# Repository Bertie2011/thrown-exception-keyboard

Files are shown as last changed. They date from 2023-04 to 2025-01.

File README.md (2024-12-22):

# ThrownException Keyboard
This repository documents all the details of my every-day keyboard and keymap.
> I use both Bertie2011 and ThrownException as online nicknames

The list of sections below will start with the keymap and QMK libraries, followed by each of the keyboards I have built (newest first).

**Click on any of the images below for more information!**

## Keymap
Many keymaps make use of holding keys to distinguish from their tap behavior. However, holding keys really sucks! For me it feels like tapping two keys is less effort than holding a key. So the philosophy behind the keymap is to be **strictly tap only**. If you're curious about how that's possible and which tricks were pulled to make it easier to use click the image below.

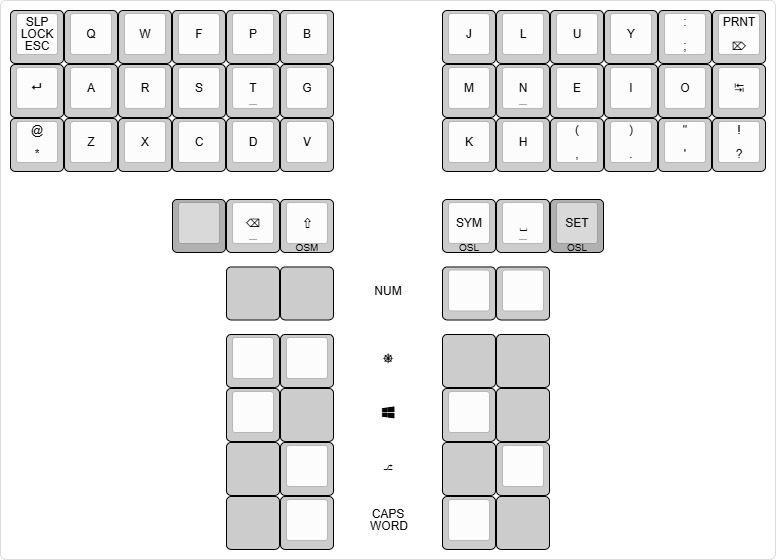
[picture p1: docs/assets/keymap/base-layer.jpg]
Keymap


## QMK Libraries
As a programmer, I love customizing QMK to the point where my keymap.c was feeling a bit too cramped to fit all the custom code. I have isolated my keymap features into seperate source files (aka "mini QMK libraries", aka "bags of tricks") so that others can use them too.

[View QMK Libraries](/qmk-lib/README.md)

## Aurora Corne V1.1 - splitkb.com
With frequent moving of the keyboard between home and work, the rotary encoders were the first to break. I also didn't get much use out of the trackpad, since it requires lifting your hand and at that point you might as well reach for the mouse. A break in the audio jack connections was the final straw. It was time for a new keyboard and I have been wanting a 6th column for a while, so coming from a trusted vendor, the choice for the Aurora Corne was made.

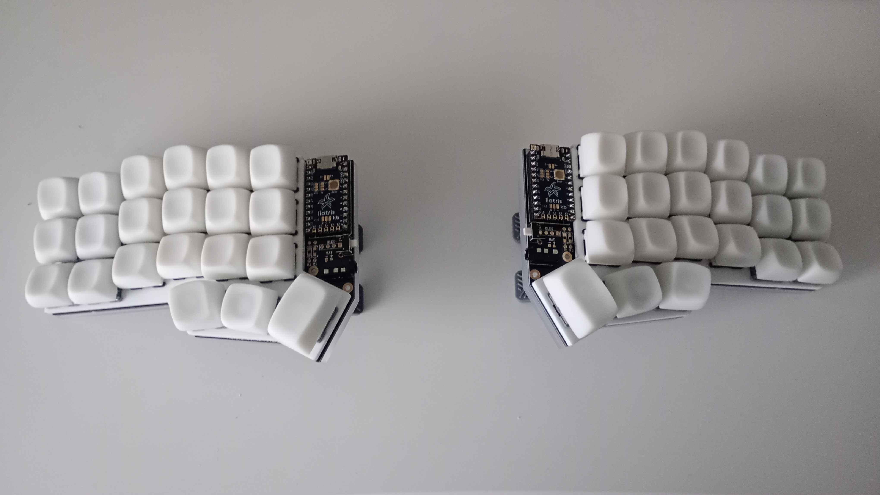
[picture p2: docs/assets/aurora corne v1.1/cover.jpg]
Aurora Corne V1.1


## Dilemma V2 - Bastard Keyboards
Since getting my first split keyboard I never stopped trying to optimize my keymap to the point that the most noticeable discomfort was having to switch over to the mouse every now and then. I tried mouse keys, but could never get used to them so I started looking at the keyboards offered on bastardkb.com. The OLED displays were only used for layer/mod indicators, which I thought would be easier to spot if the keys themselves lit up as indicators with RGB. Throw in rotary encoders which I didn't have before and the decision was made.

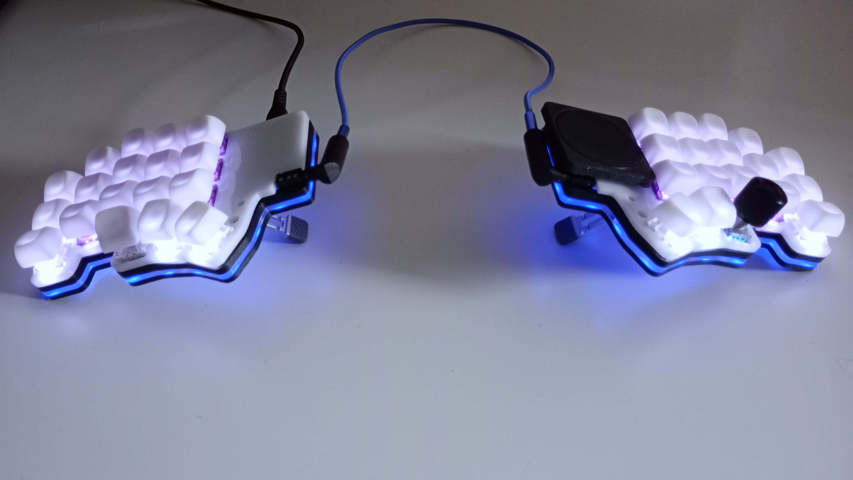
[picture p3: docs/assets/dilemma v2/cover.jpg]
Dilemma V2


## Kyria rev2.0 - splitkb.com
As a programmer I need to be able to type comfortably for many years. To avoid RSI related problems in the future, I wanted to stay ahead and get a more ergonomic keyboard. It was perfect timing, because I was transitioning from a laptop to a gaming PC at the same time, so I needed a new keyboard anyways.

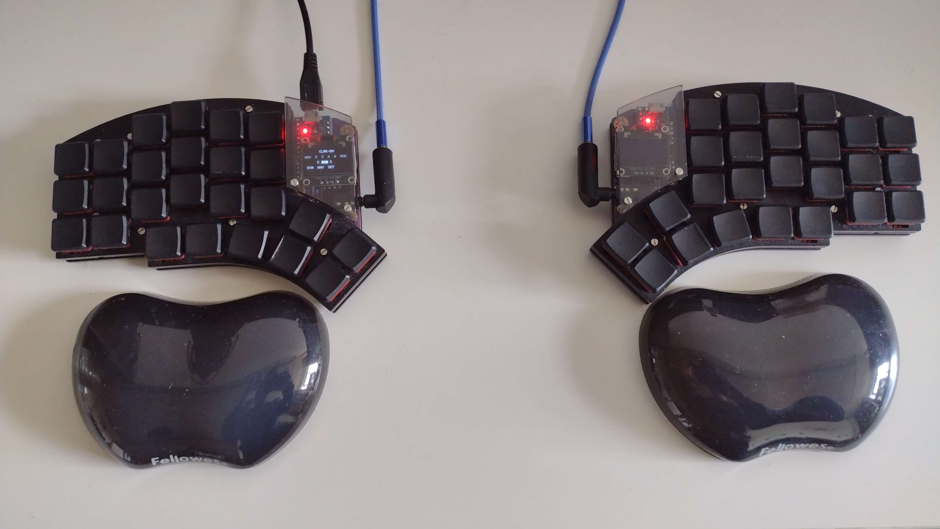
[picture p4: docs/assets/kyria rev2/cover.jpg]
Kyria rev2


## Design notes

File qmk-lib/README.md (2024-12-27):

# QMK Libraries

While working on customizing my keymap I have isolated some parts of code so they could be reused by others. Check out the table below for a list of features you can start using yourself:

Feature|Description
--:|:--
[RGB Layers](/qmk-lib/rgb-layers/)|Allows you to easily define color codes per key per layer, Ergodox EZ configurator style!
[OSM](/qmk-lib/osm/)|My own implementation of one shot modifiers, swapping out the timeout timer with a reset button and using real modifiers that the operating system picks up on as soon as the modifier key is pressed.
[Zones](/qmk-lib/zones/)|Splitting up a layer into multiple others and adding some custom code on top can allow you to repeat keypresses on one layer, while still having access to the base layer when you need it.<br><br>Unfortunately this feature only has docs with code examples and doesn't come with a simplified library that you can download.
[Utility Functions](/qmk-lib/utility-functions/)|A few miscellaneous functions, currently only consisting of improved (base) layer detection functions.

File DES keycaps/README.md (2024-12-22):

The keycaps I'm using have a DES profile. The original design files are hosted at [pseudoku/PseudoMakeMeKeyCapProfiles](https://github.com/pseudoku/PseudoMakeMeKeyCapProfiles), which were then exported as STL, touched up and uploaded at [sporkus/PseudoMakeMeKeyCapProfiles](https://github.com/sporkus/PseudoMakeMeKeyCapProfiles). I made some modifications so that I could order them from a resin printing service online.

Modifications:
- After opening them in the often already installed Microsoft 3D Builder app, I clicked on the popup that appears to "repair" each of the files.
- Added some supports for resin prints.
- Combined models of various files together for the Corne expansion file.

After printing, cleaning up any left-over supports is easiest by taking some scissors and placing each leg on either side of one of the keycap walls underneath the support strands. Then use the scissors as a lever to push the support material off. Optionally sand the bottom of the keycap afterwards.

## File combinations
By printing or ordering certain combinations of files you can get yourself a full keycap set.

* Dilemma or other 5x3+3 keyboards
    * [1x 10 Row 2](./DES_r2_1.00u_x10.stl)
    * [1x 10 Row 3](./DES_r3_1.00u_x10.stl)
    * [1x 10 Row 4](./DES_r4_1.00u_x10.stl)
    * [1x Ergo Fanned Thumb Set](./DES_thumb_ergo_1u_fanned.stl)
*  (Aurora) Corne, 5x3+3 or 6x3+3 versions
    * [1x 10 Row 2](./DES_r2_1.00u_x10.stl)
    * [1x 10 Row 3](./DES_r3_1.00u_x10.stl)
    * [1x 10 Row 4](./DES_r4_1.00u_x10.stl)
    * For 6x3: [1x 6 Column Set](./DES_column_r2r3r4_1.00u_x6.stl)
    * [1x Corne Thumb Set](./DES_thumb_corne_high_pro_x2.stl)

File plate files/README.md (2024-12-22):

# Custom Plate Files
Plate files are used to create sandwich-style cases for keyboards. Each keyboard requires a bottom and a top plate for each side (so 4 plates total). The folders you see represent different types of keyboards, if a folder doesn't contain all required plate files then you should order any remaining plates from the official vendor. Please read the documentation within the folders before ordering the plates.

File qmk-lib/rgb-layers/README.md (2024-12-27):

# RGB Layers
With RGB Layers you can define an rgb color code for every key per layer, similar to the ZSA Oryx configurator (from the same company as Ergodox EZ and Moonlander). 

> You're going to need a few kilobytes of space for this feature. It might not fit on a Pro Micro based controller.

## Setting up
To get started, follow these instructions:

* Copy the `x_rgb.h`, `x_rgb.c` and `rgb_matrix_user.inc` files to your keymap folder.
* Add to rules.mk:
   ```
   SRC += x_rgb.c
   RGB_MATRIX_CUSTOM_USER = yes
   ```
* Add to config.h:
    ```C
    #define SPLIT_LAYER_STATE_ENABLE // Sync information between both halves of split keyboard.
    #define SPLIT_MODS_ENABLE
    #define SPLIT_LED_STATE_ENABLE
    #define ENABLE_RGB_MATRIX_SOLID_COLOR
    #define ENABLE_RGB_MATRIX_CYCLE_LEFT_RIGHT
    #define X_LAYER_EFFECT_DEFAULT 0xRRGGBB // hex color code, but replace # with 0x
    ```
* Check out the other RGB [configuration options](https://docs.qmk.fm/#/feature_rgb_matrix?id=additional-configh-options) (including default mode and brightness)
* At the top of your `keymap.c` add:
    ```C
    #include "x_rgb.h"

    void keyboard_post_init_user(void) {
        x_rgb_set_layer(); // Switches to the custom RGB layers mode.
    }
    ```

## Defining color maps
In order to specify colors per key per layer, you must define the RGB maps which look a lot like your `keymaps`. For example on a simple 3 key macropad, you might want to assign red/green/blue for each of the keys like this:

```C
// You should have your keymap already defined somewhere
const uint16_t PROGMEM keymaps[][MATRIX_ROWS][MATRIX_COLS] = {
    [LAYER_BASE] = LAYOUT(
        KC_X, KC_C, KC_V
    )
};
// Now define the rgbmaps variable like this:
const uint32_t PROGMEM rgbmaps[MAX_LAYER][MATRIX_ROWS][MATRIX_COLS] = {
    // Use the same layer/layout templating syntax, but use color codes instead of key codes (in 0xRRGGBB format).
    [LAYER_BASE] = LAYOUT(
        0xFF0000, 0x00FF00, 0x0000FF
    )
};
```

## Color Aliases
The following aliases are available that you can use instead of color codes.

Alias|Value|Description
--:|:--|:--
`OOOOOOOO`|0xFFFFFF|White
`XXXXXXXX`|0x000000|Black
`________`|0x000001|Transparent (See below)

> NOTE: The aliases are 8 characters wide. Don't get them confused with the 7 character wide key code aliases.

## Overrides, defaults and underglow LEDs
Extra functions can be implemented to supply overrides and defaults on top of the RGB color maps. This can also help you implement dynamic underglow LEDs, since they cannot be addressed in the `rgbmaps` variable.

To understand how the color of a key is determined, have a look at the following list. Starting from the top, the first item that isn't returning transparent ( `________` ) will define the color.

1. Color override function (great for modifier indicators or other special events):
    ```C
    uint32_t x_rgb_get_override_color_user(led_data* data) {
        // Calculate override color here.

        return ________; // Fall back to the next color input
    }
    ```
2. Color codes in the `rgbmaps` definition. If an LED is not mapped to a key (e.g. because it's part of underglow), then this step will be skipped.
3. Color default function (great for creating layer specific underglow LED colors):
    ```C
    uint32_t x_rgb_get_default_color_user(led_data* data) {
        // Calculate override color here.

        return ________; // Fall back to the next color input
    }
    ```
4. The `#define X_LAYER_EFFECT_DEFAULT 0xRRGGBB` option in your `config.h`.
5. The color Black.

The `led_data` object can be accessed like this: `data->row`. You can find all fields below.
Field|Description
--:|:--
`row` and `col`|Defines the vertical and horizontal indexes in the key matrix. This does not necessarily match the position of the keycode in the keymap. Read up on it [here](/qmk-lib/understanding-key-indexes.md). These values will be equal to `NO_LED` if the LED is not associated with a key (e.g. for underglow or indicator lights).
`index`|The number that identifies the LED.
`x` and `y`|The physical position of the LED on the keyboard, not restricted by any grid or key indexes.
`flags`|See QMK [RGB Matrix Flags](https://docs.qmk.fm/#/feature_rgb_matrix?id=flags).

## Switching color modes
The built-in switching RGB mode key codes only switch the RGB mode, but do not switch between different saturations or values that were distinct between RGB modes. This proved troublesome, since both the solid color and the color cycle effects turn fully white with saturation 0 (while only the solid color effect was intended to be white).

So I added a few functions that switch both the RGB mode and the saturation/value/hue, which can be used with [Macros](https://docs.qmk.fm/feature_macros#using-macros-in-c-keymaps) aka custom keycodes.

Function|Description
--:|:--
`x_rgb_set_white()`|Switches to the solid color effect with hue/saturation set to 0 (white) and copying the current value (brightness). These changes are not saved to EEPROM and will revert after rebooting the keyboard loses power.
`x_rgb_set_cycle_left_right()`|Switches to the rainbow cycle effect, setting saturation to max (255) and copying the current value (brightness). These changes are not saved to EEPROM and will revert after the keyboard loses power.
`x_rgb_set_layer()`|Switches to layered RGB mode, does not modify anything else.

## Selecting colors from your keyboard
You might be curious what a color would look like on your keyboard. The library has an `x_rgb_send()` function, which prints the currently selected color, so you can make a layout that lets you browse through all the different colors and then simply type out the color into your keymap. Start by finding a spot to define the following keymap:

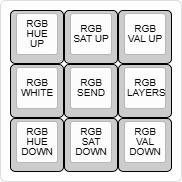
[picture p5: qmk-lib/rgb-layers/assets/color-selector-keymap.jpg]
Keymap example
  
Which should look a little like this:
```Cpp
const uint16_t PROGMEM keymaps[][MATRIX_ROWS][MATRIX_COLS] = {
    [<LAYER>] = LAYOUT(
        RM_HUEU,        RM_SATU,        RM_VALU,
        CKC_RGB_WHITE,  CKC_RGB_SEND,   CKC_RGB_LAYER
        RM_HUED,        RM_SATD,        RM_VALD
    )
};
```
The top and bottom rows are built-in keycodes to adjust hue, saturation and value (brightness). The middle row has Macros that allow setting the RGB modes and printing the hex code. You can create the macros like this:
```C
enum custom_keycodes {
    CKC_RGB_WHITE = SAFE_RANGE,
    CKC_RGB_LAYER,
    CKC_RGB_SEND,
};

bool process_record_user(uint16_t keycode, keyrecord_t *record) {
    if (record->event.pressed) {
        if (keycode == CKC_RGB_WHITE) {
            x_rgb_set_white();
            return false;
        } else if (keycode == CKC_RGB_LAYER) {
            x_rgb_set_layer();
            return false;
        } else if (keycode == CKC_RGB_SEND) {
            x_rgb_send();
            return false;
        }
    }

    return true;
}
```

After flashing your new keymap, you can use the middle left button to switch to the white solid color mode, then press the top middle (increase saturation) and top right (increase brightness) buttons until a nice color appears. Use the buttons in the top and bottom rows to find the perfect color and then press the middle button to automatically start typing the associated hex code (`0xRRGGBB`).

Do note that the color you see will be the color that's shown when your keyboard is on max brightness. So if you want max brightness colors at max brightness keyboard, then make sure to increase the value (top right button) to 100% before saving the color code.

If you want more granular levels of color adjustment, you can add the following defines to your config.h file:
```C
#define RGB_MATRIX_HUE_STEP 4 // Default: 8
#define RGB_MATRIX_SAT_STEP 8 // Default: 16
#define RGB_MATRIX_VAL_STEP 8 // Default: 16
```

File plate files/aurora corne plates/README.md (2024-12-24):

# Custom Aurora Corne Plates

These files have been sourced from the [SplitKb repository](https://github.com/splitkb/aurora/tree/master/Aurora%20Corne).

Modifications:
- The bottom plate with added kerf still had the pre-kerf lines, which I removed.
- Removed the puck hole on the bottom plate
- Removed the puck mounting points on the top plate and restored the switch holes.
- Increased the mounting point radius from 1mm to 1.5mm, because that were the requirements of the acrylic cutting company I used.
  - :warning: In hindsight, the holes are barely small enough to prevent the vendor-provided screws from passing though. If you can, I would recommend shrinking the holes back to 1mm radius.
  - Using these files with MX switches requires you to use 8mm spacers (less wobbly case, but the screws might fall out during transport) or 12mm spacers (tight screws, but plates are able to wobble up and down a bit) from the SplitKb hardware kit.
  - If you use 12mm spacers (10x) you won't have enough for the OLED covers if you got those in your kit. You do have enough 8mm spacers if you decided to use OLED covers without displays, even if you use 8mm spacers for the plates already. 
- Removed the two mounting points between the ring finger and pinky columns, because after making them bigger I deemed them too close to some of the switch holes.

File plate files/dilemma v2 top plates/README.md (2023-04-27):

# Top Plate Files
My first keyboard had acrylic plates between the PCB and the key switches. I wanted to achieve the same thing with the Dilemma, so I designed new plate files.

Some **important** notes:
* The plate files are untested.
  * I ordered an earlier revision with a miscalculated trackpad cut-out and had to remove one of the trackpad legs. The files have been adjusted and *should* fit now.
* These files are for the Dilemma V2 from bastardkb.com
* Cut-outs have been made for the keys, TRRS jack, reset button, case screws and the trackpad, but other features like the DBG/IO/LCD/I2C headers and the tenting puck mounting holes will be covered.
* You must order one of each file
* The plates should be about 4mm thick
* Make sure to check whether the plates are glossy/mat on both sides. If they are glossy on one side and mat on the other, you will have to mirror one of the files.
* :warning: Solder the reset button before adding the plate and switches!
* :warning: Insert the case screws (**with** spacers on other side) before adding the plates and soldering switches.
  * The holes are big enough to fit a hex key in, but you cannot pass screws through the plates.
  * Don't forget that the left side will need an extra flat headed screw + spacer in one of the trackpad mounting holes, because it won't be occupied by the trackpad holder. Reference the bottom case print for mounting points. You won't be able to access this screw after adding the plate.
  * Make sure to tighten the spacers on the other side of the PCB for each of the screws before continuing.

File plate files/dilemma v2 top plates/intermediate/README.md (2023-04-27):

# Intermediate top plate files
While working on creating the plate files, I made copies of my work in progress in case I wanted to rollback part of it. The files here are numbered by version (progression), starting at 1.

> :warning: **DO NOT ORDER PLATES USING THESE FILES**

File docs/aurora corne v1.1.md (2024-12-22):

# Aurora Corne V1.1 - splitkb.com
With frequent moving of the keyboard between home and work, the rotary encoders were the first to break. I also didn't get much use out of the trackpad, since it requires lifting your hand and at that point you might as well reach for the mouse. A break in the audio jack connections was the final straw. It was time for a new keyboard and I have been wanting a 6th column for a while, so coming from a trusted vendor, the choice for the Aurora Corne was made.

Aurora Corne V1.1

## Material List
If you want to build this keyboard yourself, here's what you need:
* [Aurora Corne PCB Kit](https://splitkb.com/products/aurora-corne), with RGB underglow and backlight, no OLED displays. Choc/MX Hand solder version.
* 2x [Liatris Microcontroller](https://splitkb.com/products/liatris), no sockets.
* 2x [Mill Max Low Profile Sockets](https://splitkb.com/products/mill-max-low-profile-sockets?variant=47060695646555), set of sockets with headers.
* [Aurora Low Profile Case Hardware Kit](https://splitkb.com/products/aurora-corne-low-profile-case?variant=43446809035011)
* 2x [3mm White Acrylic top plates](https://kunststofplatenshop.nl/product/plexiglas-wit-3mm/) and 2x [3mm Frost Opal White bottom plates](https://kunststofplatenshop.nl/product/plexiglas-3-mm-frost-opaalwit/). Find the plates [here](../plate%20files/aurora%20corne%20plates/).
* At least 18 [Akko V3 Silver Pro Switches](https://akkogear.de/en/collections/linear-switches/products/v3-silver-pro-switch-45pcs) and at least 24 [Akko Penguin Switches](https://akkogear.de/en/collections/tactile-switches/products/akko-penguin-switch-silent-45pcs)
* [DES keycaps](/DES%20keycaps), view the README for the list of files you need. I had them printed by [JLCPCB](https://3d.jlcpcb.com/3d-printing-quote) in 9600 Resin with sanding.
* [Braided TRRS Cable](https://splitkb.com/collections/keyboard-parts/products/braided-trrs-cable?variant=31226379468877) with [Set of Angled TRRS Adapters](https://splitkb.com/collections/keyboard-parts/products/angled-trrs-adapter)
* [1m USB C to USB A Cable](https://www.amazon.nl/dp/B0CY5N7SDC)
* 2x [Set of 2 phone stands](https://www.amazon.nl/dp/B0DMV5N17J)

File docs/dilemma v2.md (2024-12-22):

# Dilemma V2 - Bastard Keyboards
Since getting my first split keyboard I never stopped trying to optimize my keymap to the point that the most noticable discomfort was having to switch over to the mouse every now and then. I tried mouse keys, but could never get used to them so I started looking at the keyboards offered on bastardkb.com. The OLED displays I had before were only used for layer/mod indicators, which I thought would be easier to spot if the keys themselves lit up as indicators with RGB. Throw in rotary encoders which I didn't have before and the decision was made.

Dilemma V2

## Material List
If you want to build this keyboard yourself, here's what you need:
* [Dilemma Kit](https://bastardkb.com/product/dilemma/), with 2x Rotary encoders (MX), Frost case and Per-key RGB.
* [3mm Opal White Acrylic top plates](https://kunststofplatenshop.nl/product/plexiglas-opaalwit-3mm/), these plates have a light transmittance of 32% and have been designed by myself. You can view the plate files [here](../plate%20files/dilemma%20v2%20top%20plates/).
* [Akko CS Lavendar Purple Switch (Lubed, 45pcs)](https://akkogear.de/en/products/akko-cs-lavender-purple-switch-lubed-45pcs), a light tactile switch. Akko has a US based website too.
* 2x [10 pcs Gateron Switches](https://aliexpress.com/item/32791600556.html), I got white/clear gateron switches which are light linear switches. I put these on the thumb keys and the two outer columns, with the purple Akko switches everywhere else.
* [DES keycaps](/DES%20keycaps), I had them printed by [JLCPCB](https://3d.jlcpcb.com/3d-printing-quote) in 8111X Resin with sanding.
* [4 black knobs](https://www.amazon.nl/dp/B015IGMWTC?language=en_GB&th=1), these actually didn't fit the 6 mm shaft on the rotary encoders because of the plastic housing inside. I could expand the inner diameter with some course sandpaper though.
* [Braided TRRS Cable](https://splitkb.com/collections/keyboard-parts/products/braided-trrs-cable?variant=31226379468877) and [Set of 90° Angled TRRS Adapters](https://splitkb.com/collections/keyboard-parts/products/angled-trrs-adapter)
* [1m USB C to USB A cable](https://www.amazon.nl/dp/B07K4J6HJ3?language=en_GB)
* [Set of 2 Pack Foldable Feet for Keyboard Notebook](https://www.amazon.nl/-/en/Laptop-Riser-Foldable-Keyboard-Notebook/dp/B0C68V47ZT), although I currently have 1 stand on each side, I would recommend buying 2 pairs for added stability.

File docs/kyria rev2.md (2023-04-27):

# Kyria rev2.0 - splitkb.com
As a programmer I need to be able to type comfortably for many years. To avoid RSI related problems in the future, I wanted to stay ahead and get a more ergonomic keyboard. It was perfect timing, because I was transitioning from a laptop to a gaming PC at the same time, so I needed a new keyboard anyways.

Kyria rev2

## Material List
Although I got the rev 2.0 kit, these are the components you'll need if you wanted to build a similar style using the rev 3.0 kit.

* [Kyria rev3 PCB kit](https://splitkb.com/collections/keyboard-kits/products/kyria-rev3-pcb-kit), no RGB underglow, no RGB backlight, with a set of OLED displays, Choc/MX Hand solder
* 2x [Pro Micro Controller](https://splitkb.com/collections/keyboard-parts/products/pro-micro-atmega32u4-5v-16mhz), the space ended up being quite limiting especially if you want to enable most QMK features and have RGB/OLED animations. For my purposes, being a beginner of QMK and keeping everything quite simple it had just enough memory. Do check out the [Liatris Controller](https://splitkb.com/collections/keyboard-parts/products/liatris) with 16 MB of memory compared to only 32 KB on the pro micro.
* [Controller Sockets without pins](https://splitkb.com/collections/keyboard-parts/products/mill-max-low-profile-sockets), adding sockets should allow for easy removal of controllers in case they break.
* 5x [10x Kailh Low Profile Choc Switches](https://splitkb.com/collections/switches-and-keycaps/products/kailh-low-profile-choc-switches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), I got the Pro Red linear switches. Make sure you get about 55 switches for the 50 key keyboard, a few extras are good to have.
* 5x [10x 1u Blank MBK Choc Low Profile Keycaps](https://splitkb.com/collections/switches-and-keycaps/products/blank-mbk-choc-low-profile-keycaps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), on top of the 50 1u black keycaps I also got 2 sets of 2x 1u homing keycaps (for both index fingers and both thumbs).
* [Braided TRRS Cable](https://splitkb.com/collections/keyboard-parts/products/braided-trrs-cable?variant=31226379468877)
* Micro USB to USB A cable for a Pro Micro controller or a USB C to USB A cable for the Liatris controller
* [Low Profile Case](https://splitkb.com/products/kyria-rev3-low-profile-case), consisting of black Top Plate and Bottom Plate (without Puck holes), Tinted OLED Cover and a Case Hardware Kit.
* [Pair of Crystals Gel Flexible Wrist Rest](https://splitkb.com/collections/keyboard-parts/products/crystals-gel-flexible-wrist-rest), which can also be used as make-shift tenting solution :)
* [Keycap and Switch Puller](https://splitkb.com/products/switch-and-keycap-puller?variant=33314105753677)

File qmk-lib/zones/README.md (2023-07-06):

# Zones
While designing my keymap I quickly realized that the modifier keys won't fit on the base layer (I didn't like the timing issues of home row mods). I didn't want to move them to a separate layer either, because that would cause too much layer switching.

Introducing the concept of zones: Each zone is another layer and a group of zone layers can completely cover the keyboard (as if it was just 1 layer). Using custom code pressing a key in one zone, will turn the others off. That way each zone can be used repeatedly, while always having access to the base layer when you need it, without having to deactivate the zone layer explicitly.

Let's assume we have a nav bar zone (delete, tab, esc), a mod zone and we fill the remaining space with special characters. 
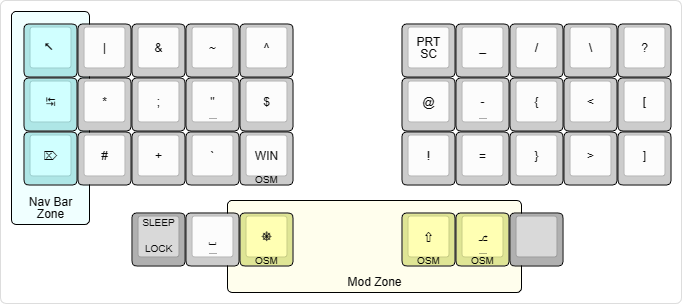
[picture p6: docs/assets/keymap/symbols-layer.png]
Symbols Layer


The zone concept makes the following example sequences work:

* Delete characters and type new text:
  * `SYM` (turns all zones on)
  * `DEL` (causes symbols and mod zones to turn off)
  * `DEL` (repeat as much as needed, the navbar zone is still available)
  * start typing (now the navbar zone turns off)
  * the base layer is completely uncovered now, all zones have been turned off
* Save all files in editor:
  * `SYM` (turns all zones on)
  * `CTRL` (causes navbar and symbols zones to turn off)
  * `SHIFT` (mod zone was still on)
  * `S` (now mod zone turns off as well)
  * the base layer is completely uncovered now, all zones have been turned off

## Implementing into your keymap
Unfortunately I haven't written a generic reusable solution for this yet, but here are some pointers to get started.

First start by defining a new layer with keycodes for each of the zones you have in mind. Make sure to fill overlapped slots with `_______` (transparent), so that the zone layers can be stacked on top of each other to form one full layer.

Make sure to copy [the layer detection](/qmk-lib/utility-functions/) functions into your keymap.

Then add a [custom keycode](https://docs.qmk.fm/#/custom_quantum_functions?id=custom-keycodes) that toggles all your layers on and off.

```C
enum keys {
    CC_LAYER_SYM = SAFE_RANGE,
};

enum layers {
    LAYER_BASE = 0,
    // ...
    LAYER_SYMBOLS,
    LAYER_NAV_BAR,
    LAYER_MODS
};

// Layers use bitflags, which is basically saying that each bit (0 or 1) in a number is used as a boolean indicator (a flag).
// The line below creates a bitflag where the bits for each of zones is turned on.
const int LAYER_SYM_MASK = (1 << LAYER_SYMBOLS) | (1 << LAYER_NAV_BAR) | (1 << LAYER_MODS);

bool process_record_user(uint16_t keycode, keyrecord_t *record) {
    uint8_t row = record->event.key.row;
    uint8_t col = record->event.key.col;
    bool pressed = record->event.pressed;

    if (pressed && keycode == CC_LAYER_SYM) {
        if (layer_mask_enabled_any(LAYER_SYM_MASK)) {
            layer_and(~LAYER_SYM_MASK);
        }
        else layer_or(LAYER_SYM_MASK);
        return false;
    }
    
    return true;
}
```

> Now would be a good time to test!

Before continuing, make sure that you have a good understanding of how the position of a keycode in the keymap relates to the row/column indexes. Read up on it [here](/qmk-lib/understanding-key-indexes.md).

Now we can implement code to turn each of the zones off automatically. Note that deactivating a zone layer with `pressed == true` will deactivate the layer before QMK has a chance to find the keycode that belongs to the key. Deactivating with `pressed == false` (on release) would still allow that layer to be used for finding the related keycode.

```C
bool process_record_user(uint16_t keycode, keyrecord_t *record) {
    uint8_t row = record->event.key.row;
    uint8_t col = record->event.key.col;
    bool pressed = record->event.pressed;

    bool releaseBeforePress;
    bool releaseAfterPress;

    releaseBeforePress = ...; // Which keys will cause the layer to deactivate before being handled
    releaseAfterPress = ...; // Which keys will cause the layer to deactivate after being handled

    if (layer_enabled(<zone layer>) && keycode != CC_LTG_SYM && <key check>) {
        layer_off(<zone layer>);
    }

    // ... the custom keycode implementation should be here ...
}
```

Now replace `<key check>` with one of the following examples, or come up with your own:

Boolean Condition | Description
--:|:--
`pressed == releaseBeforePress` | Any keys matched by `releaseBeforePress` will cause the layer to deactivate before processing the keys, all others will deactivate the layer on release. This can simulate a one shot layer.
`((pressed && releaseBeforePress) \|\| (!pressed && releaseAfterPress))`| This condition will make sure that all keys detected by `releaseBeforePress` will deactivate the layer first before processing the key press. Any other keys detected by `releaseAfterPress` will deactivate the layer after processing the key press. Any key presses detected by neither of boolean value will keep the layer activated. Each of the boolean values can just be set to `false` to not match any key presses.

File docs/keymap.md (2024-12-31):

# ThrownException Keymap
When doing a deep dive into small keyboard keymaps, a lot of them seem to rely on holding keys, whether that's for switching layers, using modifiers or simply fitting another special character on the same key. 

This didn't feel right for me, because when I decide I want to put something on the screen, I only want to to think about what to do and not how to do it. I want my input to be instant and not be dependent on any kind of delay. Also the effort of holding a key and pressing another seems to be more than the effort of pressing two or even three keys shortly.

## Philosophy
* Use the Colemak Mod-DH base layout for improved ergonomics
* Avoid holding keys at all costs for instant input and decreased effort
* Avoid thinking about which layers were activated earlier, only think about the next key.
  * All layers can be activated from any other layer, no need to disable a layer first
  * The [symbols layer](#symbols-layer) has a special implementation that allows repetition and base layer access at the same time. 
* Exclusive layers, only 1 extra layer can be active at a time

## QMK Libraries
My keymap contains some custom code. If you want to really understand what's going on or would like to try out some unique features for yourself, check out my [QMK lib folder](/qmk-lib/README.md).

## Base Layer
This layer is based on Colemak Mod-DH. Although I got a little creative with the symbols, my favorite being the parentheses instead of angle brackets above the comma and period. The thumb keys are occupied by backspace, one shot shift, symbols layer and space keys. The thumb keys have several combos for the other modifiers, the numbers layer and caps word functionality. The top left corner has escape, (using SHIFT) screen lock and (using CTRL) sleep keys. The top right corner has delete and (using SHIFT) printscreen keys.

Base Layer

## Symbols Layer
The symbols layer consists of a clear distinction between halves, on the left there is a navigation cluster and the right is filled with symbols. The outer columns and thumb cluster (and its combos) share similarities with the base layer. Custom code is used so that the layer will only automatically deactivate when symbols, F-keys or thumb keys are pressed.

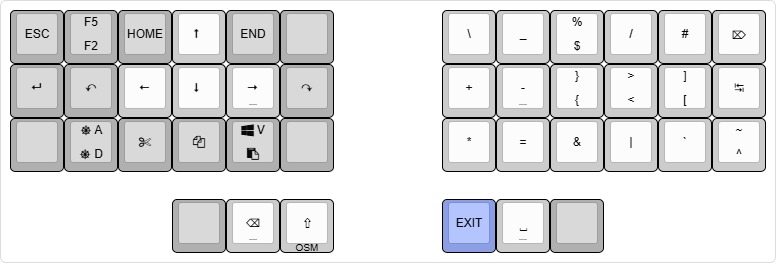
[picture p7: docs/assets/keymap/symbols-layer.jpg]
Symbols Layer


### Navigation Cluster
On the left you can see the arrow keys, surrounded by cut/copy/paste (WIN+V invokes the built-in clipboard history) and home/end (jump to start/end of line) keys. In the surrounding columns you can find the undo (CTRL+Z), redo (CTRL+Y), rename (F2), refresh (F5), select next occurrence (CTRL+D) and select all (CTRL+A) shortcuts. I placed the `/` on this side as well so I could (un)comment code using only one hand.

### Symbols
Some insights on why I picked these positions for the symbols
* I'm a programmer, so access to brackets is important. I put the opening brackets on the home row, because editors often auto complete the closing brackets.
* Logic operators & (`and`) and | (`or`) are next to each other.
* Backtick shares the same key as the other quote types underneath.
* Symmetry with both types of slash characters.
* Least frequently used characters share the same keys, which can be accessed using CTRL/SHIFT.

## Numbers Layer
This layer has a numpad on the right. It shares the parentheses, thumb keys and some of the outer column keys with the base layer. It's worth noting that the period key is specifically the numpad version, which most apps should translate to the appropriate decimal separator (comma or period) depending on the locale. On the left you can find the common arithmetic operators as well as shortcuts for manipulating the memory (based on the Windows calculator app) and copy/paste keys in the same location as the symbols layer.

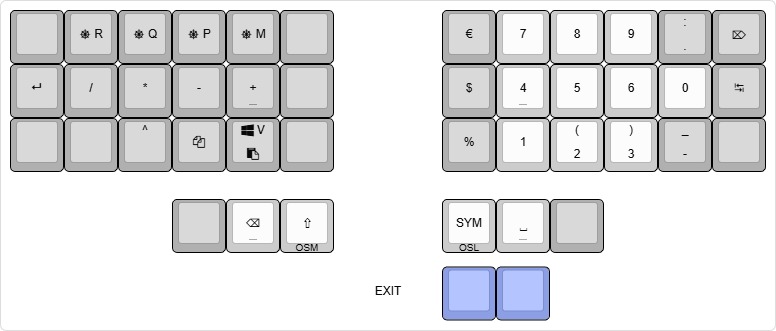
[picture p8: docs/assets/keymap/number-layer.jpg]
Numbers Layer


## Settings Layer
The settings layer only contains F-keys, some locking keys and keys for controlling RGB settings.

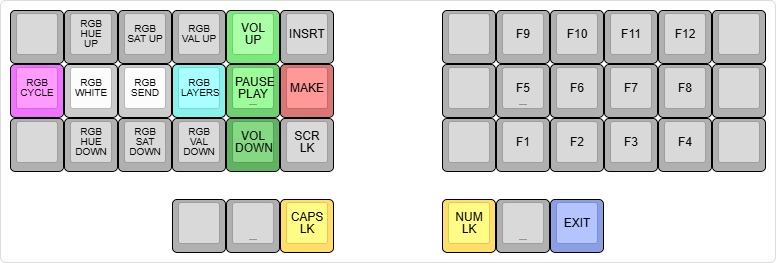
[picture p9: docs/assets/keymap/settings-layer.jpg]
Settings Layer


## Game Layer
The outer thumb key on the symbol layer will cause the keyboard to switch to this base layer. It's a simple QWERTY base layer with the left hand shifted over to bring WASD under the correct fingers. It also has another column on the left with commonly used modifier keys.

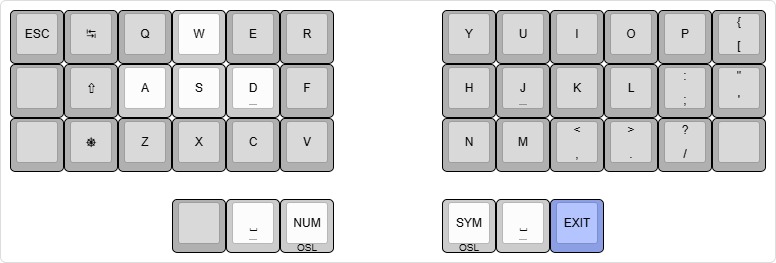
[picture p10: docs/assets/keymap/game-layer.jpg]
Game Layer


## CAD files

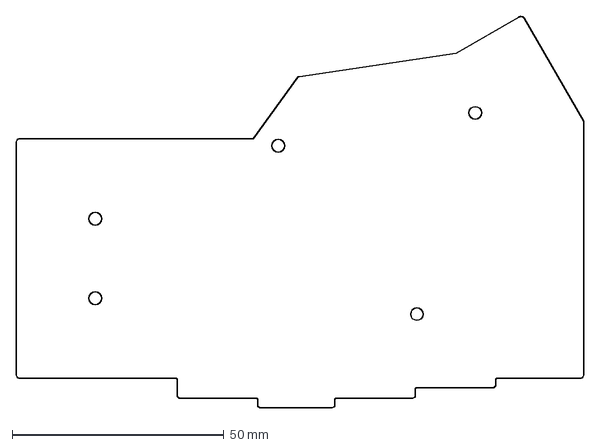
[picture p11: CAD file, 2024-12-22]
plate files/aurora corne plates/Aurora Corne Bottom Plate - 0.1mm Kerf.dxf
133.9 x 92.4 mm

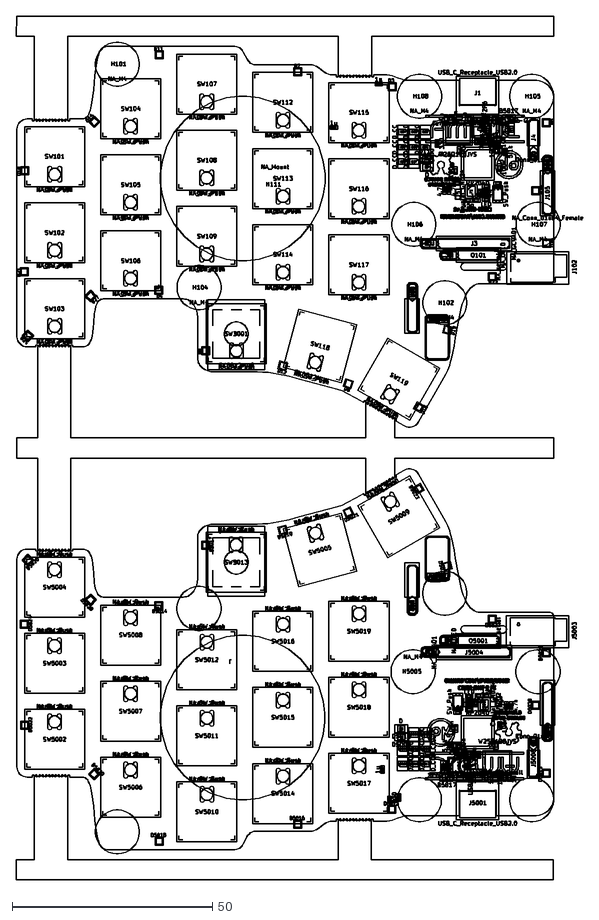
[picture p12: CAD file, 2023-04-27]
plate files/dilemma v2 top plates/intermediate/0 dilemma-brd-unmodified.dxf
141.3 x 215.6

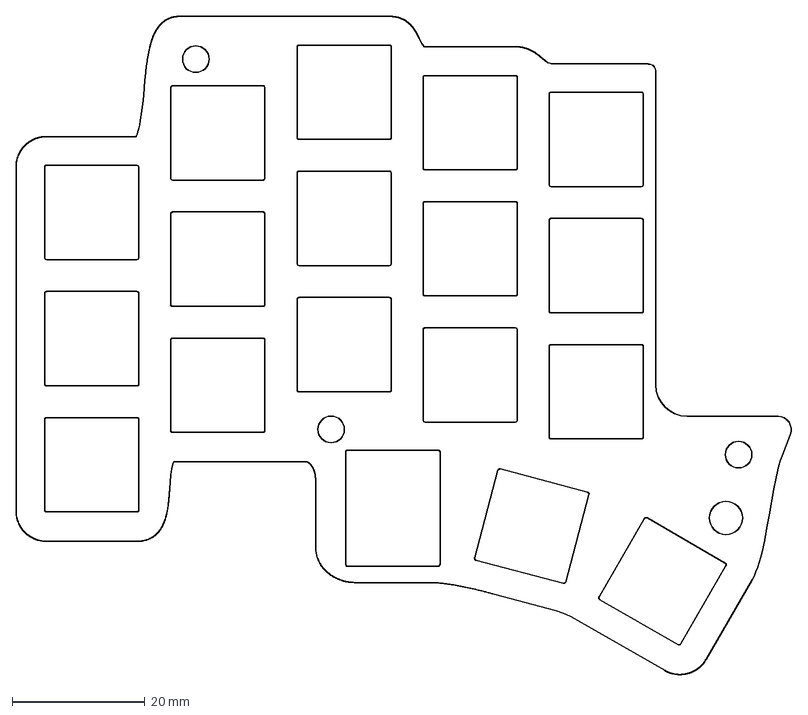
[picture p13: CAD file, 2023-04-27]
plate files/dilemma v2 top plates/top-plate-with-trackpad.dxf
116.9 x 99.1 mm

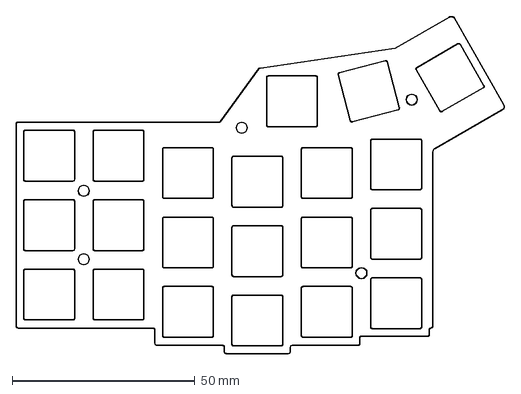
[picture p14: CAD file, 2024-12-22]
plate files/aurora corne plates/Aurora Corne Top Plate - 0.1mm Kerf.dxf
133.8 x 92.3 mm

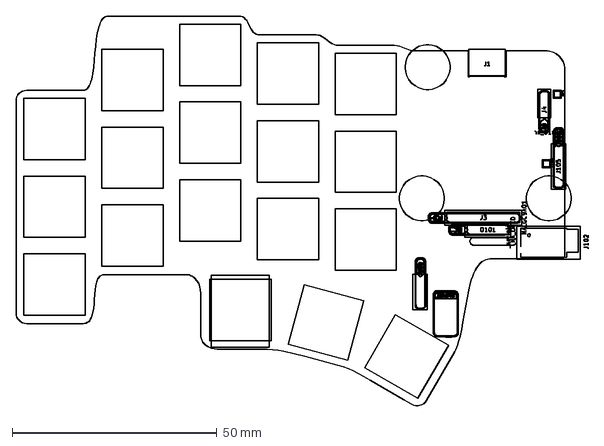
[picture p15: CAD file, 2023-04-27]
plate files/dilemma v2 top plates/intermediate/1 dilemma-brd-clean.dxf
139.7 x 95.1 mm

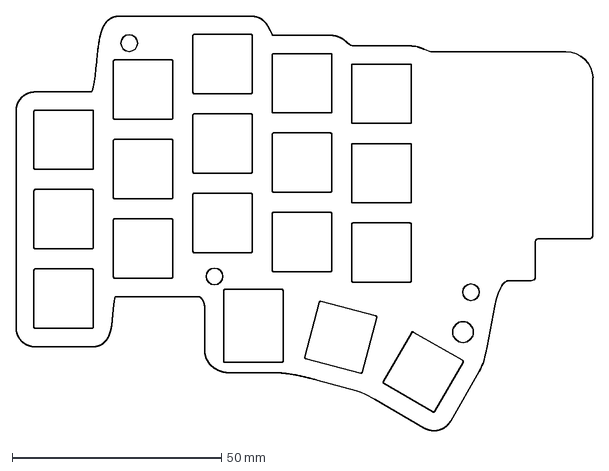
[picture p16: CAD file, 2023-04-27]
plate files/dilemma v2 top plates/top-plate-without-trackpad.dxf
138.0 x 99.1 mm

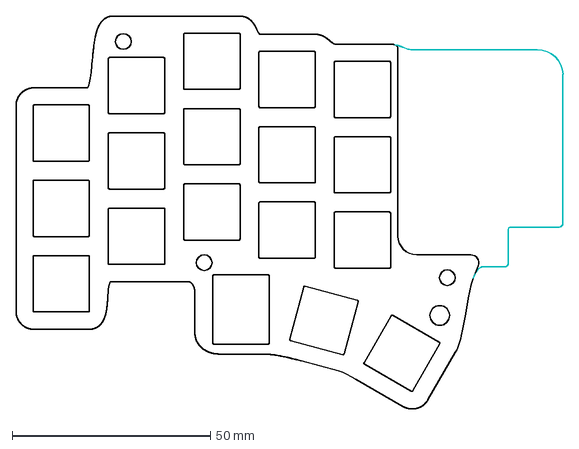
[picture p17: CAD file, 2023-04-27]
plate files/dilemma v2 top plates/intermediate/3 dilemma-brd-make-cut-ready.dxf
138.0 x 99.1 mm

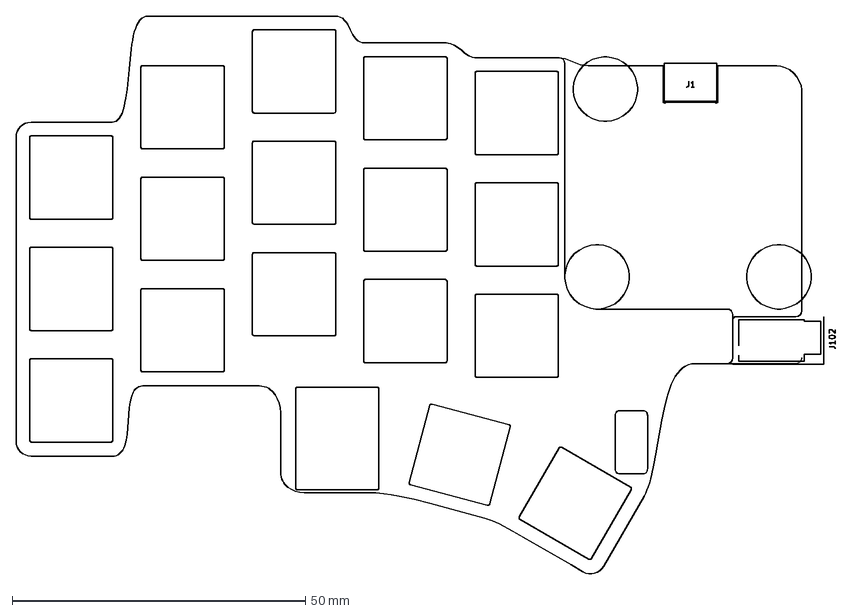
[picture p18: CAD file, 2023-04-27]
plate files/dilemma v2 top plates/intermediate/2 dilemma-brd-cut-outs-only.dxf
139.7 x 95.1 mm

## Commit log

2023-04-27 Documented my keymap, first two keyboards and the plate files!
    [0 dilemma-brd-unmodified.dxf, 1 dilemma-brd-clean.dxf, 2 dilemma-brd-cut-outs-only.dxf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]
2023-08-02 Removed a knob and used the button for settings
2024-12-22 Added aurora corne plates and keycaps, reorganized + new readmes
    [0 dilemma-brd-unmodified.dxf, 1 dilemma-brd-clean.dxf, 2 dilemma-brd-cut-outs-only.dxf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]
2024-12-22 Added material list aurora corne
2024-12-24 Added cover image and info on which spacers to use.
2024-12-27 Added functionality to send current color.
2025-01-20 Tap & Hold chained modifiers
